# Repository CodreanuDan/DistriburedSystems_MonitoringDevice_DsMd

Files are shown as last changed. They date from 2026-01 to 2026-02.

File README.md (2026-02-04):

# Distributed Monitoring and Control System  

## 1. Overview  
IoT-based Smart Home solution using two independent ESP32 nodes communicating in real-time via MQTT. The system monitors environmental parameters (temperature, air quality, light) and automatically controls power loads (DC motor, LED) with hysteresis logic or manual override through a Node-RED dashboard.

Block Diagram  
*System block diagram showing sensor-actuator distribution and MQTT communication*

## 2. Hardware  
Node 1 handles power control and consumption monitoring. Node 2 performs environmental data acquisition and visual feedback.

Breadboard  
*Full breadboard assembly of both nodes*

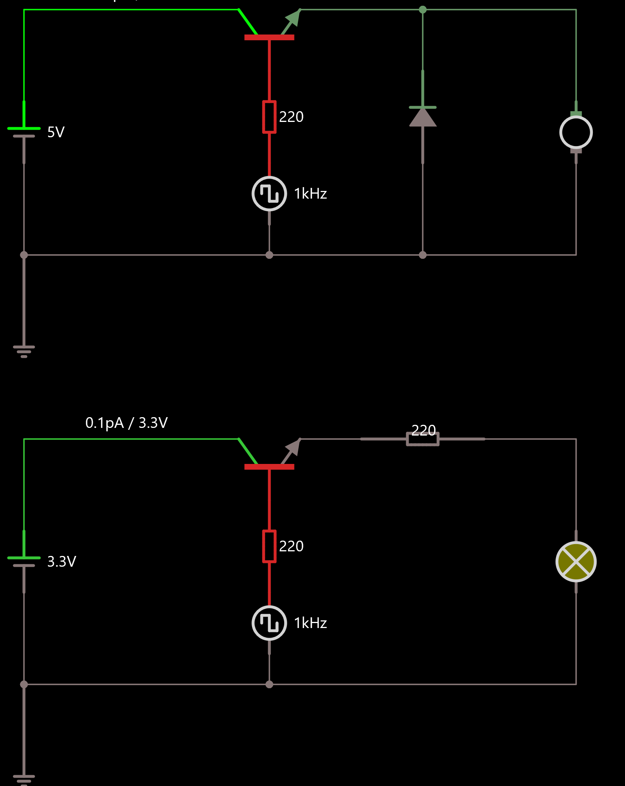
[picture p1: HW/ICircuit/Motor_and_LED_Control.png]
Motor Control Circuit; LED Control Circuit
  
*TIP142 Darlington transistor driver for DC motor with flyback diode protection; S8050 NPN transistor driver for LED control*

## 3.1 Software – ESP32 Nodes  

SW Diagram Node 1  
*Software flow for Node 1 (motor control, MAX471, LDR, WiFi/MQTT, LCD, button FSM)*

SW Diagram Node 2  
*Software flow for Node 2 (BME680 task, LED dimmer, WiFi/MQTT, LCD, button FSM)*

## 3.2 MQTT & Node-RED Dashboard  

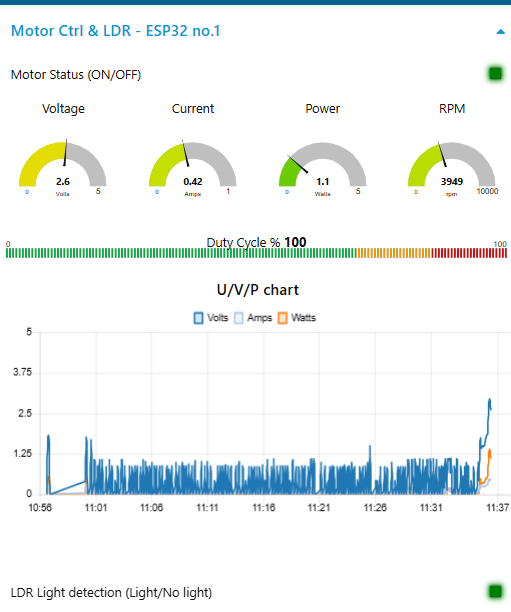
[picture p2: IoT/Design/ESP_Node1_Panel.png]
Dashboard Node 1 – Motor & LDR
  
*Real-time motor power, current, voltage and LDR status monitoring*

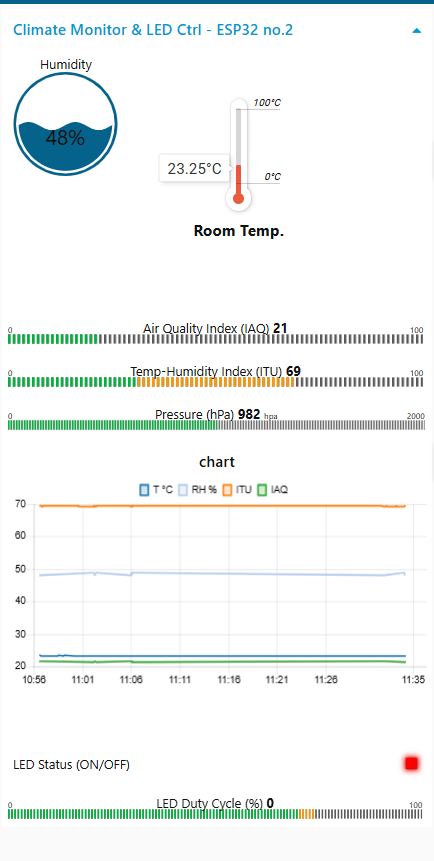
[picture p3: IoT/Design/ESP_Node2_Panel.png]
Dashboard Node 2 – Climate & LED
  
*Temperature, humidity, IAQ and LED control visualization*

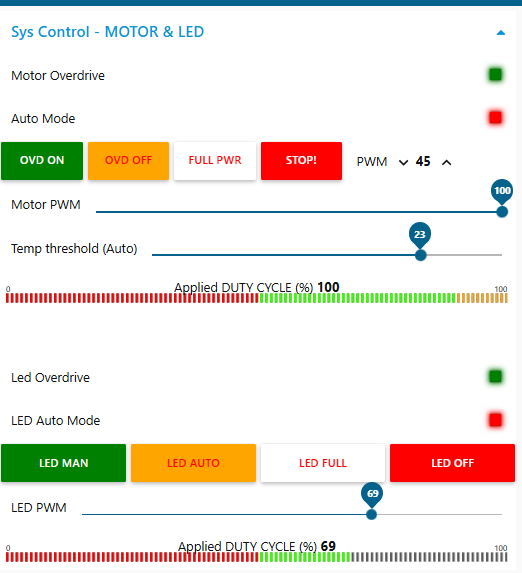
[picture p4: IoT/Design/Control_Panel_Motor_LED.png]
Dashboard Control – Motor & LED
  
*Manual/Auto mode selection and direct control buttons for motor and LED*

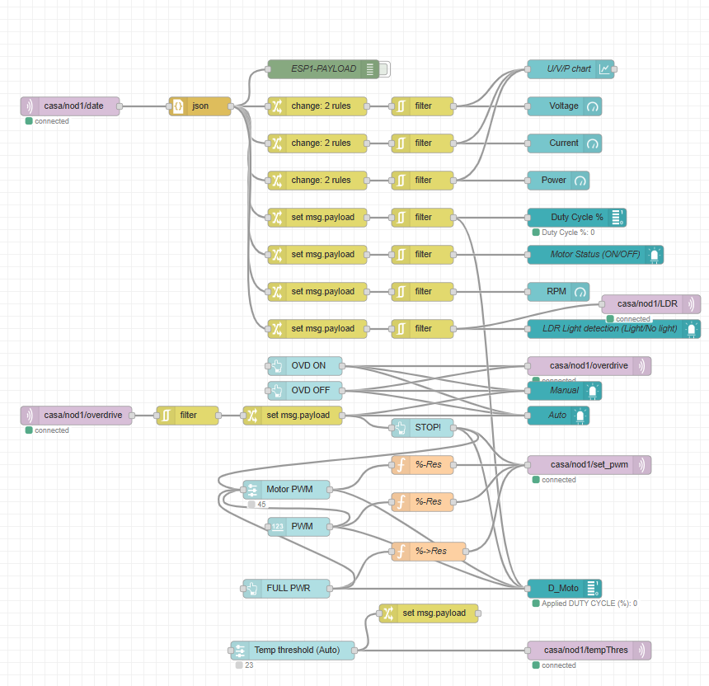
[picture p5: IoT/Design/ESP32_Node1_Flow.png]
Node-RED Flow ESP1
  
*Data processing and dashboard flow for Node 1*

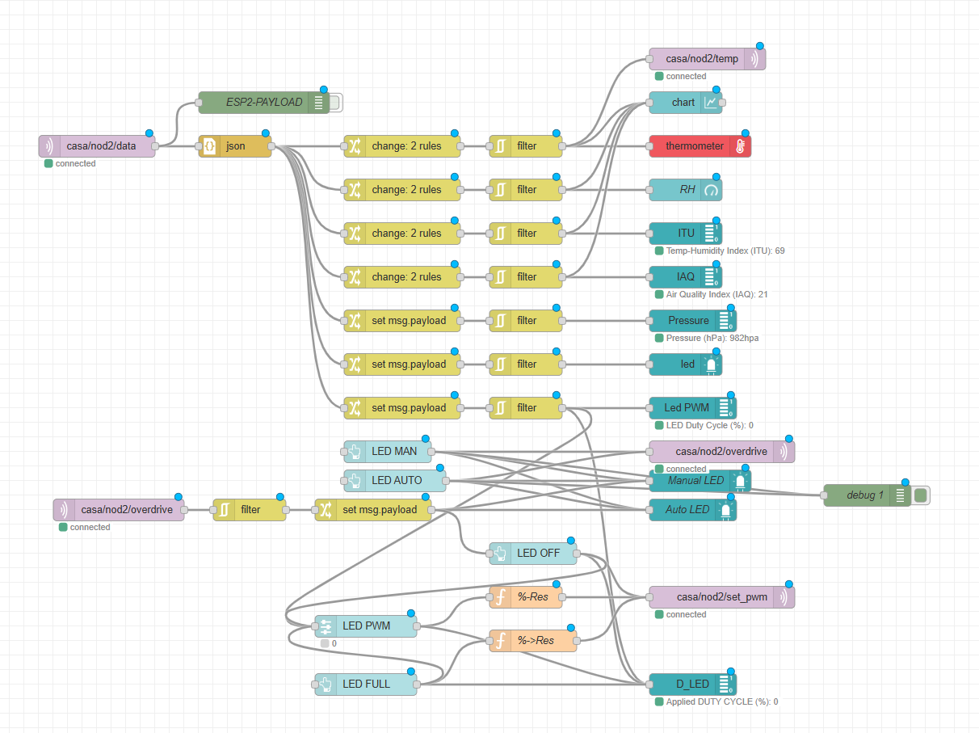
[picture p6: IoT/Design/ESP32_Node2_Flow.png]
Node-RED Flow ESP2
  
*Sensor data processing and LED command flow for Node 2*

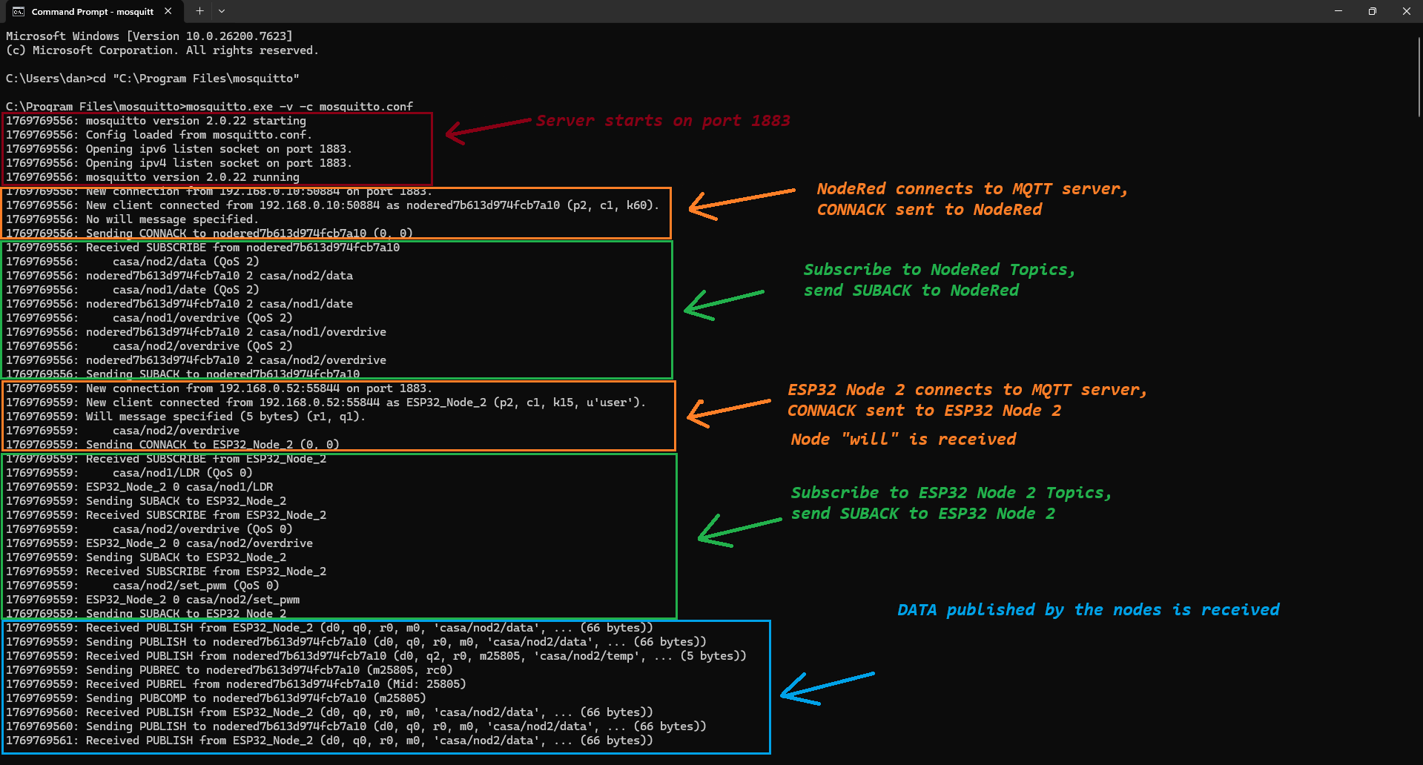
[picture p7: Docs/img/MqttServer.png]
MQTT Broker Workflow
  
*MQTT communication flow between ESP32 nodes and Node-RED dashboard*

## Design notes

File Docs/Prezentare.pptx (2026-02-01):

## Sistem distribuit de monitorizare si control

Codreanu Dan

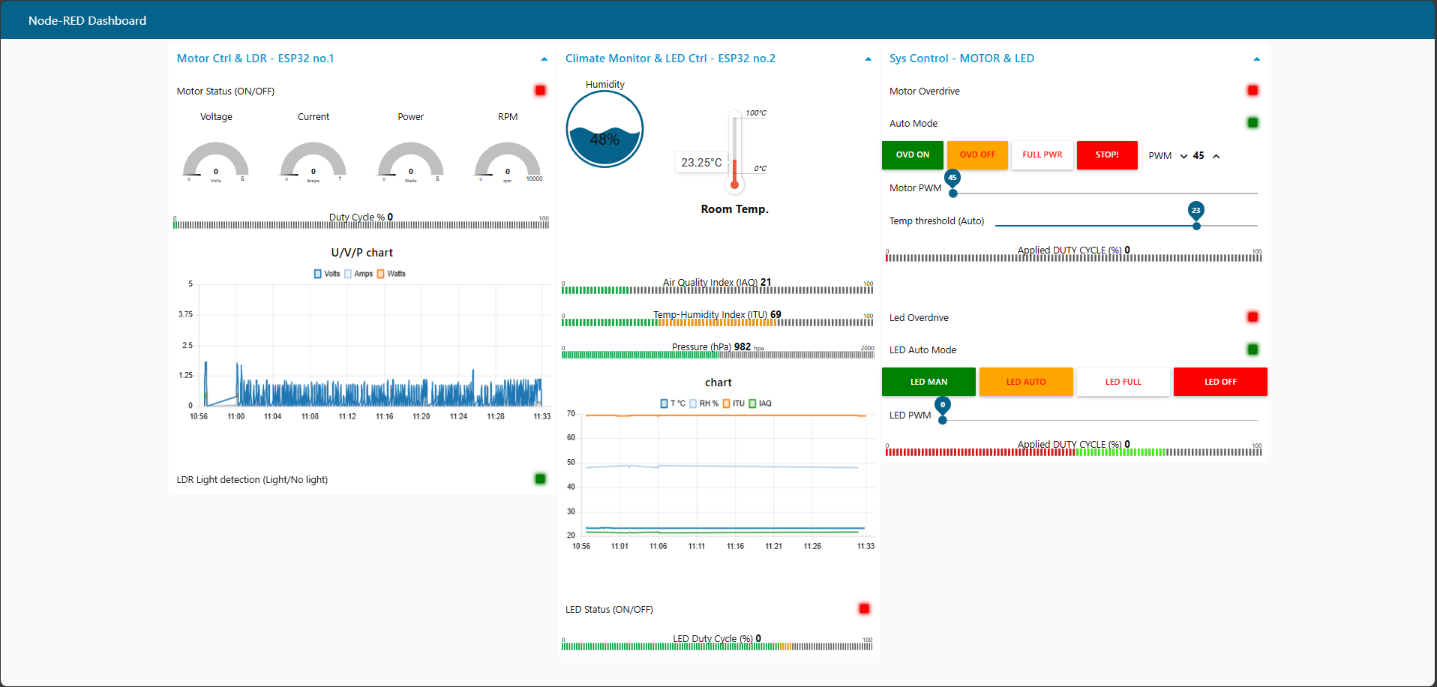
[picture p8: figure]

## Schema bloc

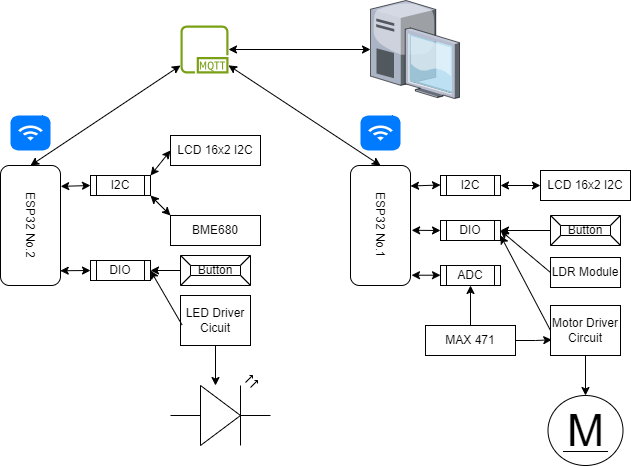
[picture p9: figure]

## Implementare fizica

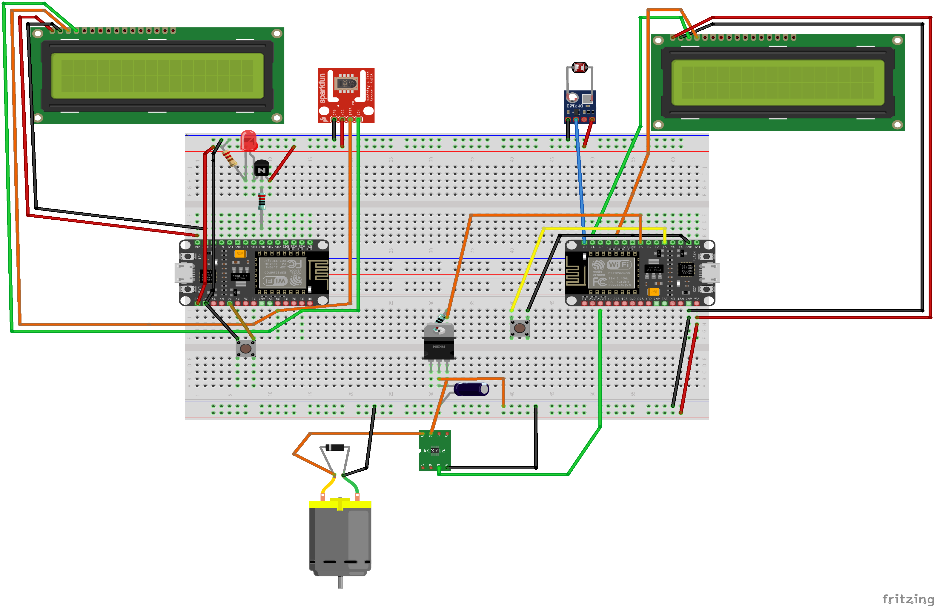
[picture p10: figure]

## Aplicatie Nod 1

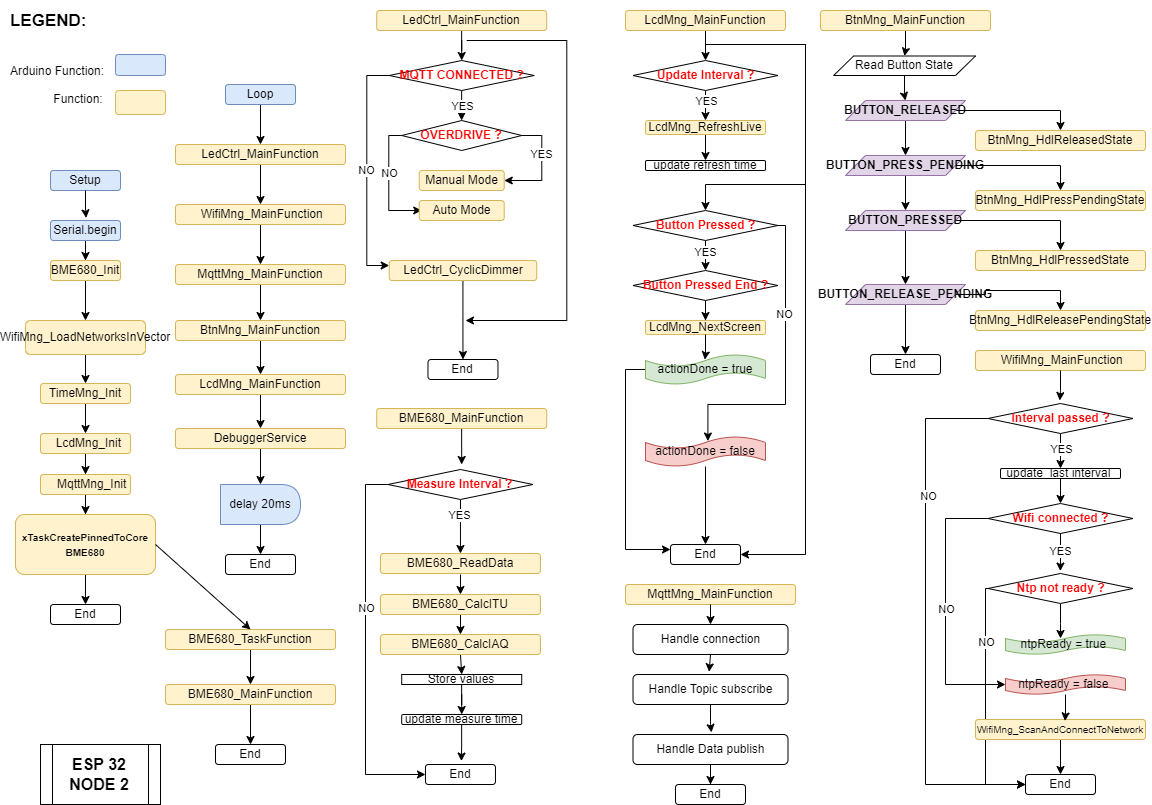
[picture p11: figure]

Aplicatie Nod 2

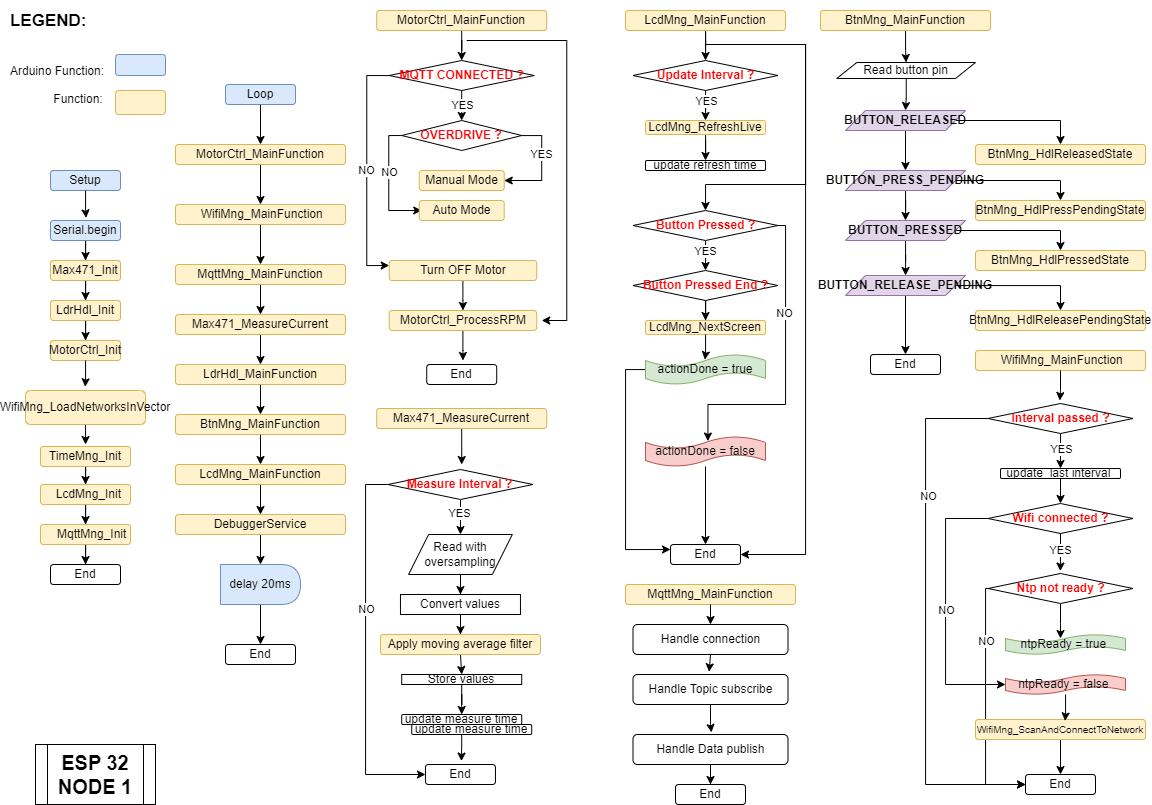
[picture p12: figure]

## Panou comanda

## Flow Nod 1


Flow Nod 2


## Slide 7


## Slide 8


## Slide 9


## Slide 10

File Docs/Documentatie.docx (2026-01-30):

Sistem distribuit de monitorizare si control

Codreanu Dan

Capitolul 1 Descriere

Sistemul propus reprezinta o solutie integrata de monitorizare si control ambiental de tip Smart Home, bazata pe arhitectura IoT (Internet of Things). Scopul principal este automatizarea climatizarii si a iluminatului intr-un spatiu interior prin comunicarea intre doua noduri inteligente independente (ESP32) care fac schimb de date in timp real prin protocolul MQTT. Sistemul nu doar monitorizeaza parametrii de mediu (temperatura, calitate aer, lumina), ci si actioneaza asupra unor sarcini de putere (motor DC, LED) intr-un mod eficient, protejand componentele hardware prin logica de control avansata.

1.1 Detalii Tehnice: Nodul 1 (Control Putere si Executie)

Acest nod este responsabil pentru gestionarea elementelor mecanice si monitorizarea consumului de energie.

- Actionare Motor: Utilizeaza un tranzistor Darlington TIP142 pentru a controla un motor DC prin PWM (1 kHz).
- Monitorizare Energie: Senzorul MAX471 masoara in timp real curentul si tensiunea consumata de motor, oferind date critice despre sarcina sistemului.
- Senzor LDR Digital: Monitorizeaza pragul de luminozitate ambientala.
- Interfata Locala: Un ecran LCD afiseaza statusul motorului, consumul de curent si starea conexiunii WiFi/MQTT.

1.2 Detalii Tehnice: Nodul 2 (Monitorizare Mediu si Feedback)

Acest nod functioneaza ca unitate de achizitie date si indicator vizual.

- Senzor BME680: Senzor de inalta precizie care furnizeaza date despre temperatura, umiditate, presiune atmosferica si calitatea aerului (IAQ - Indoor Air Quality).
- Sistem Iluminat: Un LED de controlat prin transistor prin PWM, a carui stare depinde de datele primite de la senzorul LDR de pe Nodul 1.
- Interfata Locala: Ecran LCD dedicat pentru afisarea telemetriei de mediu primite de la BME680 si starea conexiunii WiFi/MQTT.

1.3 Logica de Control si Comunicare

Interactiunea dintre cele doua noduri este mediata de un broker MQTT si un dashboard Node-RED:

1. Control Automat Motor (Histerezis): Nodul 1 primeste temperatura de la Nodul 2 si ajusteaza viteza motorului in functie de diferenta fata de pragul setat.
2. Control Automat LED : Cand senzorul LDR (Nod 1) detecteaza intuneric, se trimite o comanda MQTT catre Nodul 2 pentru a aprinde LED-ul local.
3. Supraveghere: Node-RED serveste drept interfata centrala de comanda, unde utilizatorul poate trece sistemul din modul "Auto" in "Manual" (Overdrive).

Capitolul 2 Hardware

Acest capitol descrie componentele electronice utilizate si modul in care acestea au fost integrate pentru a realiza cele doua noduri de control si monitorizare.

2.1. Unități de Procesare și Comunicare

Sistemul utilizează două unități ESP32, configurate să comunice prin protocolul MQTT. Alegerea acestora a fost motivată de prezența modulelor WiFi integrate și a pinilor hardware dedicați pentru PWM și ADC (conversie analog-digitală, Fig. 2.1).

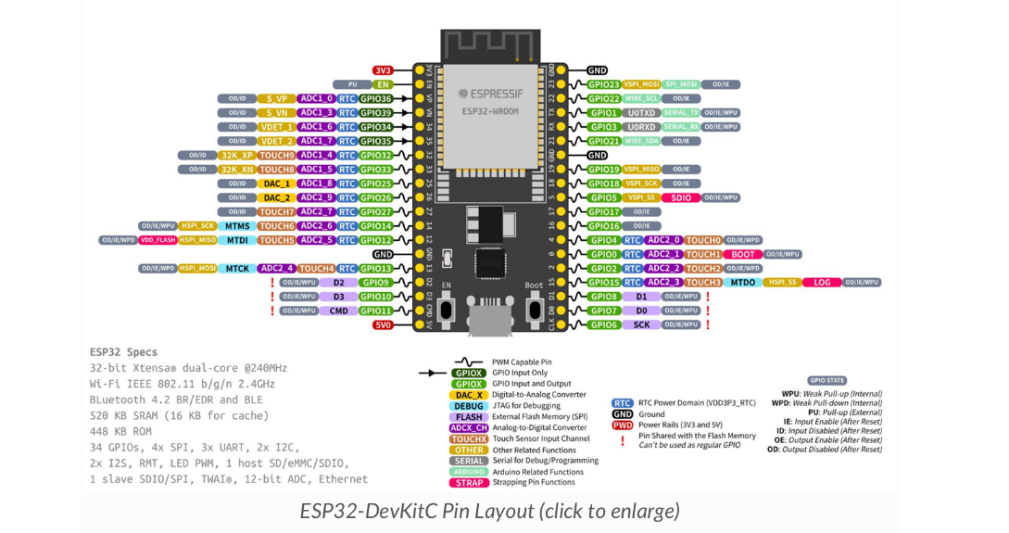
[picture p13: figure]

Fig 2.1 : ESP 32

2.2. Senzori (Achiziție Date)

Sistemul colectează date din mediul exterior prin trei senzori principali:

- BME680: Un senzor complex de mediu care măsoară temperatura, umiditatea, presiunea atmosferică și rezistența gazului (pentru calitatea aerului Tabel 2.1 si Fig. 2.2).

Parametru | Specificatie
Interfata de comunicare | I2C (pana la 3.4 MHz) si SPI
Gama masurare Temperatura | -40°C ... +85°C
Rezolutie Temperatura | 0.01 °C
Toleranta Temperatura | ±0.5 °C (la 25°C)
Gama masurare Umiditate | 0% ... 100% r.H.
Toleranta Umiditate | ±3% r.H.
Gama Presiune Barometrica | 300 ... 1100 hPa
Calitate Aer (IAQ) | 0 ... 500 (VOC - Compusi Organici Volatili)

Tabel 2.1: Specificatii BME 680

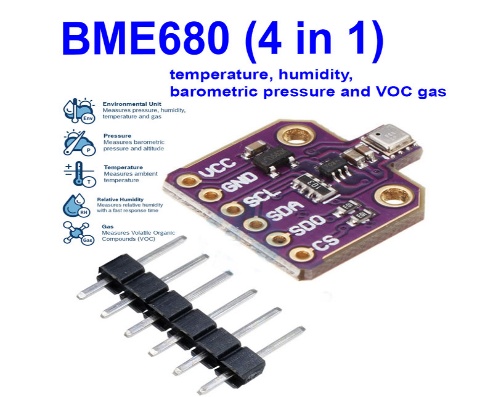
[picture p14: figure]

Fig. 2.2: Senzor BME 680

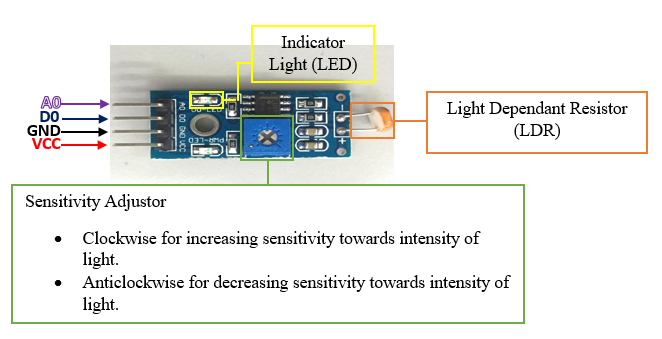
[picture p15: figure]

- LDR (Light Dependent Resistor): Modul digital care monitorizează intensitatea luminii ambientale pentru controlul automat al iluminatului (Fig. 2.2.)

Fig. 2.3: Modul sensor LDR

- MAX471: Senzor specializat pentru măsurarea tensiunii și a curentului (până la 3A). Acesta oferă feedback vital despre consumul motorului și eficiența tranzistorului de putere (Tabel 2.2 si Fig. 2.3).

Parametru | Specifitcatie
Interfata de comunicare | Analogica (Tensiune proportionala cu I si V)
Gama masurare Curent | 0A ... 3A (Sensibilitate 1V / 1A)
Gama masurare Tensiune | 3V ... 36V (Divizor intern 1:5)
Gama masurare Tensiune | ±2%
Rezolutie (pe ESP32) | 12-bit ADC (aprox. 0.8mA per unitate)
Functie principala | Monitorizare consum motor si detectie Back EMF

Tabel 2.2: Specificatii MAX 471

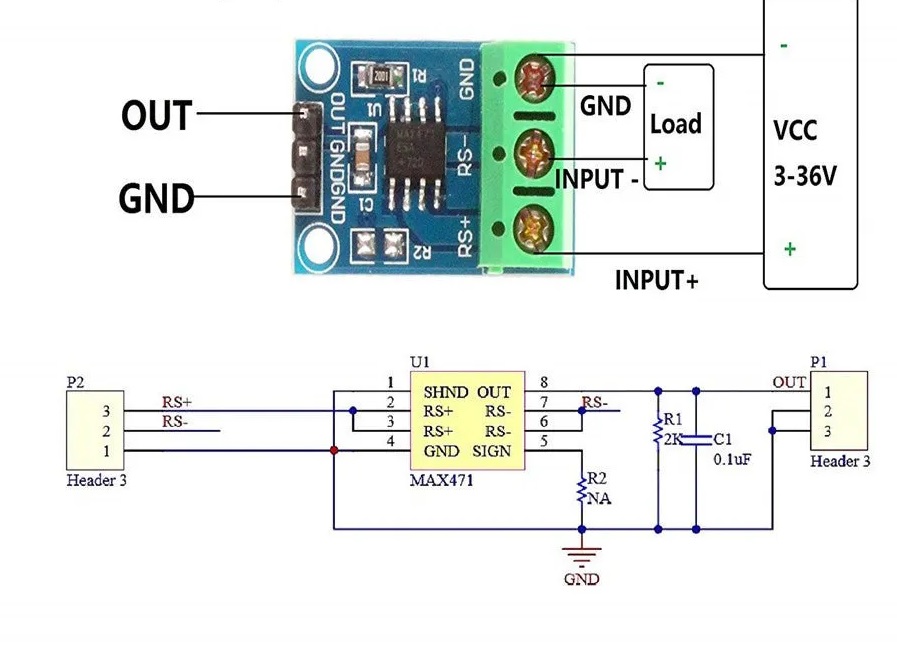
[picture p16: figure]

Fig. 2.3: Senzor MAX 471 cu schema de cablare

2.3. Actuatori și Circuite de Comandă

Elementele de execuție sunt controlate prin tranzistori pentru a izola microcontrolerul de sarcinile de putere:

1. Sistemul de Răcire (Motor DC):
  - Utilizează un tranzistor Darlington TIP142 (Fig. 2.4).
  - Motorul are o forță nominală de 10 g*cm (aprox. 0.139 oz*in).
  - Include o diodă Flyback pentru protecție împotriva tensiunii electromotoare de autoinducție (Back EMF) generate la comutația PWM.
2. Sistemul de Iluminat (LED):
  - Utilizează un tranzistor NPN S8050 (Ic max 700mA, Fig. 2.4).
  - Permite controlul intensității luminoase fără a depăși limita de curent a pinilor ESP32.

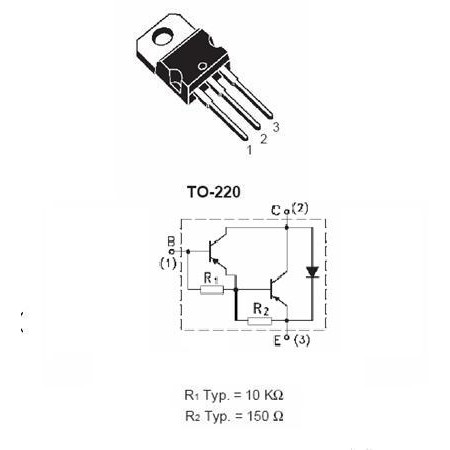
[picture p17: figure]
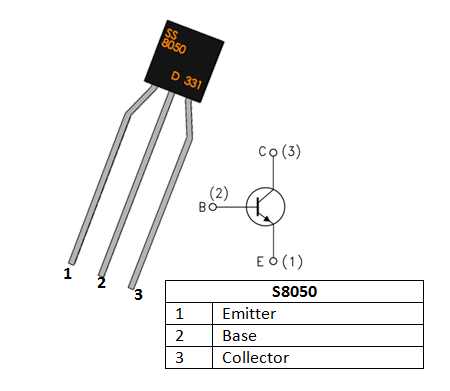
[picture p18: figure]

Fig. 2.4: Tranzistori TIP142 si S8050

2.4. Interfețe de Afișare

Sistemul dispune de două ecrane LCD 16x2 cu module I2C, care oferă feedback vizual direct (Fig 2.5) :

- Afișarea telemetriei de mediu (BME680).

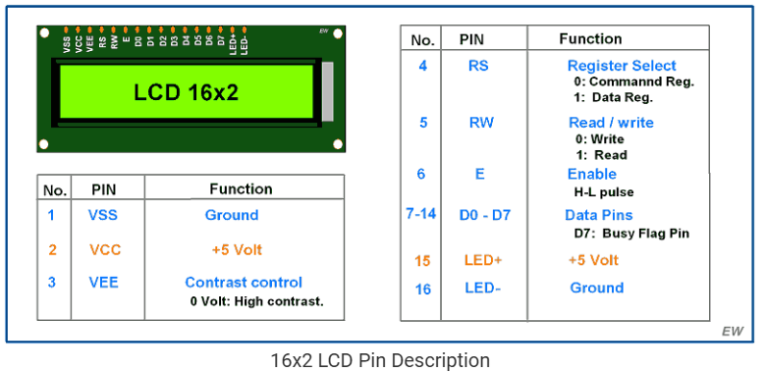
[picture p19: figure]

- Monitorizarea parametrilor electrici (V, mA, W) și a treptei PWM active.

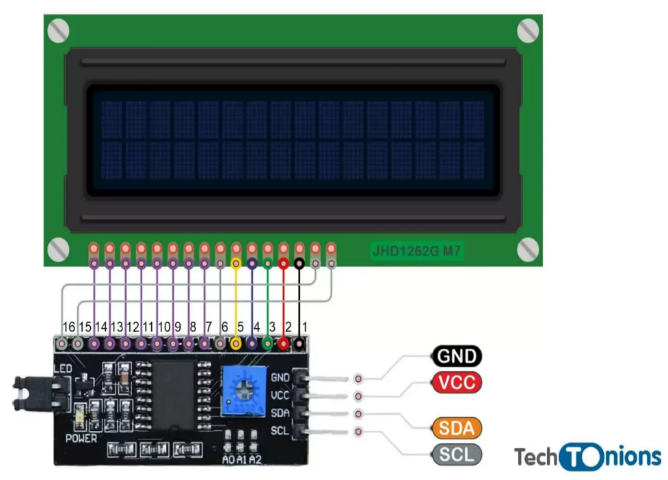
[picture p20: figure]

Fig. 2.5: Ecran LCD 16x2 LCD

2.5. Arhitectura si Conexiuni Hardware

Aceasta sectiune descrie modul in care componentele individuale interactioneaza pentru a forma un sistem unitar.

2.5.1. Diagrama Bloc a Sistemului

Diagrama bloc prezinta organizarea logica a componentelor. Aceasta pune accent pe distributia senzorilor si a elementelor de executie, fara a detalia nivelurile de tensiune, evidentiind rolul central al brokerului MQTT in comunicarea dintre cele doua unitati ESP32. (Fig. 2.6)


Fig. 2.6: Diagrama Bloc a Sistemului

2.5.2. Layout-ul General (Breadboard)

Implementarea fizica pe breadboard prezinta implementarea fizica a proiectului. (Fig. 2.7)


Fig. 2.7: Implementarea fizica pe breadboard

2.5.3. Circuitele de Comanda (Drivere Actuatori)

Sistemul utilizeaza doua circuite de comanda dedicate pentru a izola microcontrolerul de sarcinile electrice mari: (Fig. 2.8)

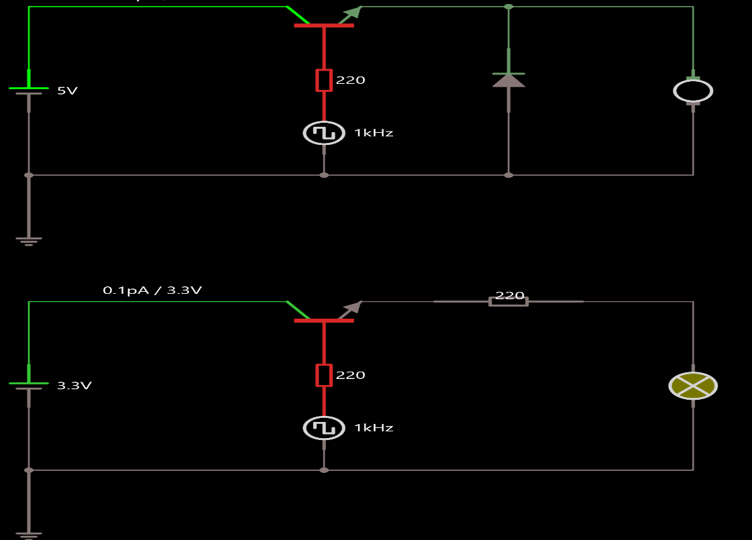
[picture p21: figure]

Fig. 2.8: Implementarea fizica pe breadboard

A. Circuitul de Comanda Motor (TIP142):

- Tranzistor: Darlington NPN TIP142.
- Functie: Controlul vitezei prin PWM (1 kHz).
- Protectie: Include o dioda Flyback montata in paralel cu motorul pentru a absorbi varfurile de tensiune generate de inductanta motorului (Back EMF).
- Monitorizare: Senzorul MAX471 este inseriat in acest circuit pentru a masura curentul consumat in timp real.

B. Circuitul de Comanda LED (S8050):

- Tranzistor: NPN S8050 de mica putere.
- Functie: Comutarea sau reglarea intensitatii LED-ului pe baza datelor primite de la senzorul LDR.
- Avantaj: Protejeaza pinul GPIO al ESP32, permitand un curent de operare mai mare decat cei 12-20mA pe care ii poate furniza direct microcontrolerul.

Nota Tehnica: Cuplul nominal al motorului este de 10 g*cm (aprox. 0.139 oz*in). In cadrul testelor, s-a observat ca la valori PWM sub 45%, forta motorului este limitata de frecarea interna si de caderea de tensiune de aprox. 1.2V pe tranzistorul TIP142.

Capitolul 3: Arhitectura Software

Sistemul utilizeaza o arhitectura modulara. Fiecare componenta hardware este gestionata de un modul software dedicat, facilitand testarea si depanarea independenta.

3.1. Module Specifice Nod 1 (Figura 3.1)

- Setup & Loop: Initializeaza perifericele(Serial.begin(115200), Max471_Init(MAX_471_PIN, ADC_RESOLUTION, ADC_0db), LdrHdl_Init(), MotorCtrl_Init(),WifiMng_LoadNetworksInVector(),TimeMng_Init(),LcdMng_Init(),MqttMng_Init()) si ruleaza secvential functiile de control la un interval de 20ms pentru a reseta Watchdog timer-ul si a nu bloca procesorul.
- Motor Control (MotorCtrl_MainFunction()): Verifica starea conexiunii MQTT si modul de operare (Manual[Overdrive:True]/Auto[Overdrive:False]). Calculeaza turatia aproximativa (MotorCtrl_ProcessRPM()) , starea curenta a motorului (MotorCtrl_CheckMotorStat(targetDuty)) si gestioneaza pornirea/oprirea motorului.
- Max471_Hdl(): Realizeaza achizitia de date prin oversampling (citiri multiple pentru precizie), converteste valorile analogice si aplica un filtru de medie mobila (moving average filter) pentru a elimina zgomotul electric cauzat de motor.
- LdrHdl_MainFunction(): Monitorizeaza intrarea digitala a senzorului de lumina pentru a determina pragul de zi/noapte.

3.2. Module Specifice Nod 2 (Figura 3.2)

- Setup & Loop: Pe langa initializarile standard, acest nod creeaza un Task dedicat pentru BME680 (xTaskCreatePinnedToCore), profitand de arhitectura dual-core a ESP32 pentru a nu bloca bucla principala in timpul citirilor lungi ale senzorului.
- LedCtrl_MainFunction(): Gestioneaza starea LED-ului. Verifica starea conexiunii MQTT si modul de operare (Manual[Overdrive:True]/Auto[Overdrive:False]). In modul "Auto", foloseste un sistem de tip Cyclic Dimmer (LedCtrl_CyclicDimmer()) pentru a regla intensitatea luminii in mod progresiv.
- BME680_TaskFunction(void * pvParameters) & BME680_MainFunction(): Citeste datele brute de la senzor, calculeaza indicii de confort (ITU) si calitatea aerului (IAQ), apoi stocheaza valorile pentru a fi publicate.

3.3. Module Comune (Partajate intre Noduri)

Aceste module asigura infrastructura de comunicatie si interfata cu utilizatorul pe ambele dispozitive:

- WifiMng_MainFunction(): Gestioneaza scanarea si conectarea si reconectarea automata la retea. Include logica de verificare a timpului prin NTP (Network Time Protocol, TimeMng_GetTimestamp()) pentru a sincroniza evenimentele.
- MqttMng_MainFunction(): Subscrie la topicurile de comanda si publica telemetria (datele senzorilor) catre broker. Gestioneaza reconectarea automata in caz de pierdere a semnalului.
- BtnMng_MainFunction(BTN_PIN, BtnMng_debounceTime): Implementeaza o masina de stare pentru tratarea apasarilor (Released, Press Pending, Pressed, Release Pending), eliminand zgomotul mecanic prin debounce.
- LcdMng_MainFunction(): Controleaza afisajul. Permite navigarea intre mai multe ecrane de date la apasarea butonului si actualizeaza informatiile in timp real la intervale setate.

3.4. Debugger Service

Fiecare nod ruleaza un serviciu de monitorizare (DebuggerService()) care trimite catre consola Seriala un raport detaliat despre starea interna a sistemului, facilitand diagnosticarea rapida fara a fi nevoie de acces fizic la ecranele LCD.

3.5. Optimizari si Tehnici de Control Avansate

Pentru a asigura stabilitatea sistemului si protectia hardware-ului, au fost implementate urmatoarele solutii software:

3.5.1. Filtrarea Datelor: Moving Average Filter si ADC Vref 1.1V

Senzorul MAX471 este montat in proximitatea motorului, fiind expus la zgomot electromagnetic. Pentru a obtine o citire stabila a curentului si a tensiunii:

- S-a utilizat tehnica oversampling-ului, citind senzorul de mai multe ori intr-un interval scurt.
- Datele sunt procesate printr-un filtru de medie mobila (Moving Average), care elimina varfurile (spike-urile) cauzate de comutatia PWM si de Back EMF, oferind o valoare "curata" pe LCD si in Dashboard.
- Tensiunea de referinta a ADC-ului este setata la 1.1V (ADC_0db) deoarece motorul foloist nu va trage mai mult de 1A, si legea de conversie fiind 1A la 1V, ajuta la o masurare mai optima.

3.5.2. Managementul PWM (1 kHz):

Frecventa semnalului PWM pentru controlul motorului a fost setata la 1 kHz cu o rezolutie de 8 biti:

- De ce 1 kHz? Aceasta frecventa este suficient de mare pentru a asigura o rotatie fluida si pentru a evita tiuitul audibil al motorului, dar suficient de mica pentru a reduce pierderile prin incalzire pe tranzistorul TIP142.
- Controlul LED-ului de pe al doilea nod utilizeaza tot PWM prin functia analogWrite(), permitand tranzitii line de luminozitate (dimming) gestionate de tranzistorul S8050.

3.5.3. Functia de Kickstart: MotorCtrl_Kickstart(targetDuty);

Motoarele DC mici au o frecare statica ce poate impiedica pornirea la valori mici de PWM (ex. 45%).

- Logica de control include un mecanism de Kickstart: la fiecare pornire din starea "Stop", motorul primeste un impuls de la 100% PWM pana la turatia setata pentru o durata foarte scurta (aprox. 100-200ms).
- Acest impuls ofera energia necesara pentru a invinge inertia, dupa care sistemul revine imediat la pragul tinta (ex. 45% sau 55%).

3.5.4. Executie Non-Blocking

O caracteristica esentiala a codului este faptul ca toate functiile sunt non-blocking:

- Nu s-a utilizat functia delay() in interiorul modulelor (cu exceptia micii pauze de 20ms din loop pentru stabilitatea generala).
- Gestionarea timpului pentru citirea senzorilor (BME680, MAX471) sau trimiterea datelor prin MQTT se face prin compararea valorilor millis().
- Acest lucru permite ESP32-ului sa raspunda instantaneu la apasarea butoanelor sau la mesajele primite de la server, chiar daca in acelasi timp proceseaza datele de mediu sau calculeaza media mobila.


Fig 3.1: Aplicatie ESP32 Nod 1


Fig 3.2: Aplicatie ESP32 Nod 2

Capitolul 4: Interfata de Control (Node-RED si MQTT)

Aceasta sectiune descrie infrastructura software de nivel inalt care asigura comunicarea, stocarea datelor si interfata grafica pentru utilizator (Dashboard).

4.1. Serverul MQTT (Mosquitto)

Serverul MQTT actioneaza ca un "broker" (intermediar) de mesaje. Acesta primeste datele de la cele doua ESP32 si le redirectioneaza catre Node-RED.

- Instalare si Rulare: S-a utilizat Eclipse Mosquitto. Instalarea pe sistemul gazda (ex: Raspberry Pi sau PC) s-a realizat prin managerul de pachete, fiind configurat sa ruleze ca serviciu de fundal pe portul standard 1883, logare tip “anonimous” pentru a nu fi nevoie de user parola si a facilita protiparea


- Rol: Asigura decuplarea completa intre noduri; ESP1 nu are nevoie sa stie adresa IP a ESP2, ambele comunicand doar cu adresa serverului MQTT. (Fig. 4.1)

Fig 4.1: Functionare Server MQTT

4.2. Platforma Node-RED

Node-RED este instrumentul de programare vizuala utilizat pentru a procesa fluxurile de date si pentru a crea interfata de control (Dashboard).

- Instalare: Rulat in mediul Node.js, instalat via npm.
- Logica de Flux (Flows): Aici am integrat diagramele de noduri pentru cele doua ESP-uri.
  - Flow ESP 1: Noduri de intrare MQTT pentru U, I, P si RPM, conectate la functii de procesare si elemente grafice.( Fig.4.2)
  - Flow ESP 2: Noduri pentru preluarea telemetriei BME680 (T, RH, IAQ, ITU) si transmiterea comenzilor catre LED. (Fig.4.3)


Fig 4.2: Flow ESP32 Node 1


Fig 4.3: Flow ESP32 Node 2

4.3. Prezentarea Dashboard-ului (Interfata Utilizator)

Dashboard-ul este impartit in trei panouri principale pentru o monitorizare clara si un control precis.

4.3.1. Panoul 1: Monitorizare Energie si Motor (Nod 1)

Acest panou este dedicat performantei electrice a motorului DC. (Fig. 4.4)

- Instrumente de masura: Gauge-uri si grafice de tip "History" pentru Tensiune (U), Curent (I), Putere (P) si RPM.
- Vizualizare Comparativa: Chart (grafic liniar) care suprapune valorile U, I si P pentru analiza eficientei.
- Indicatori Stare: O bara progresiva pentru nivelul de Duty Cycle al motorului si un LED virtual care semnalizeaza daca motorul este alimentat.


Fig 4.4: Panoul 1: Monitorizare Energie si Motor (Nod 1)

4.3.2. Panoul 2: Monitorizare Mediu si Senzori (Nod 2)

Ofera o privire de ansamblu asupra conditiilor ambientale citite de BME680 si starea luminilor. (Fig. 4.5)

- Indicatori Vizuali: "Fill tank" pentru Umiditate Relativa (RH), termometru vertical pentru Temperatura (T), bare de progres pentru calitatea aerului (IAQ), indicele de confort (ITU) si presiune.
- Istoric Date: Grafice dedicate pentru evolutia RH, T, IAQ si ITU.
- Status Sistem: Bara pentru Duty Cycle LED, LED-uri virtuale pentru starea Motor ON/OFF si un indicator pentru detectia de lumina (zi/noapte) primita de la LDR.


Fig 4.5: Panoul 2: Monitorizare Mediu si Senzori (Nod 2)

4.3.3. Panoul 3: Consola de Comanda (Control Motor si LED)

Acesta este panoul interactiv unde utilizatorul poate interveni asupra sistemului. (Fig.4.6)

Control Motor:

- Moduri: LED-uri de stare pentru modul Auto (ON/OFF) si Manual (ON/OFF).
- Comenzi Rapide: 4 butoane pentru Overdrive ON, Overdrive OFF, Full Power si Stop.
- Reglaj Fin: Control numeric pentru setarea exacta a turatiei in plaja de siguranta (45-75%).
- Interfata Tactila: Sliding bar pentru controlul vitezei (45-100%) si un sliding bar pentru setarea pragului de temperatura (Threshold 0-30°C) utilizat in modul Auto.

Control LED:

- Moduri: LED-uri pentru modul Auto/Manual.
- Comenzi Rapide: Butoane pentru Overdrive, Full Dimm (intensitate maxima) si OFF.
- Reglaj: Control numeric (45-75%) si sliding bar pentru ajustarea PWM-ului de la 0 la 100%.


Fig 4.5: Panoul 3: Consola de Comanda (Control Motor si LED)

Capitolul 5: Concluzii

Proiectul a demonstrat succesul implementării unui sistem de monitorizare și control de tip Smart Home, utilizând o arhitectură distribuită bazată pe două unități ESP32 și protocolul de comunicație MQTT.

5.1. Realizări Proiectului

- Integrare Hardware-Software: S-a reușit controlul eficient al sarcinilor de putere (motor DC și LED) prin utilizarea tranzistorilor TIP142 și S8050, protejând în același timp integritatea microcontrolerelor.
- Fiabilitatea Datelor: Implementarea filtrului de medie mobilă (Moving Average Filter) și a tehnicii de oversampling a permis obținerea unor citiri stabile de curent și tensiune, în ciuda zgomotului electromagnetic generat de motor.
- Control Inteligent: Algoritmul de control cu trei praguri și funcția de Kickstart au asigurat o funcționare fluidă a sistemului de răcire, eliminând problemele cauzate de frecarea statică a motorului la turații mici.
- Monitorizare Centralizată: Interfața Node-RED oferă o experiență de utilizare intuitivă, centralizând telemetria complexă (BME680, MAX471, LDR) într-un dashboard vizual complet.

5.2. Avantajele Arhitecturii Adoptate

Utilizarea protocolului MQTT a permis o scalabilitate ridicată. Nodurile pot fi plasate în locații diferite, singura condiție fiind accesul la rețeaua WiFi, ceea ce transformă acest proiect într-o soluție viabilă pentru automatizări rezidențiale sau industriale ușoare.


Execuția de tip non-blocking și utilizarea multithreading-ului (pe ESP32 Node 2) garantează că sistemul rămâne receptiv la comenzile utilizatorului, indiferent de complexitatea calculelor de mediu efectuate în fundal.

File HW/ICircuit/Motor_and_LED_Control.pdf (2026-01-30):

# Motor_and_LED_Control

1/29/2026 1:58:46 PM

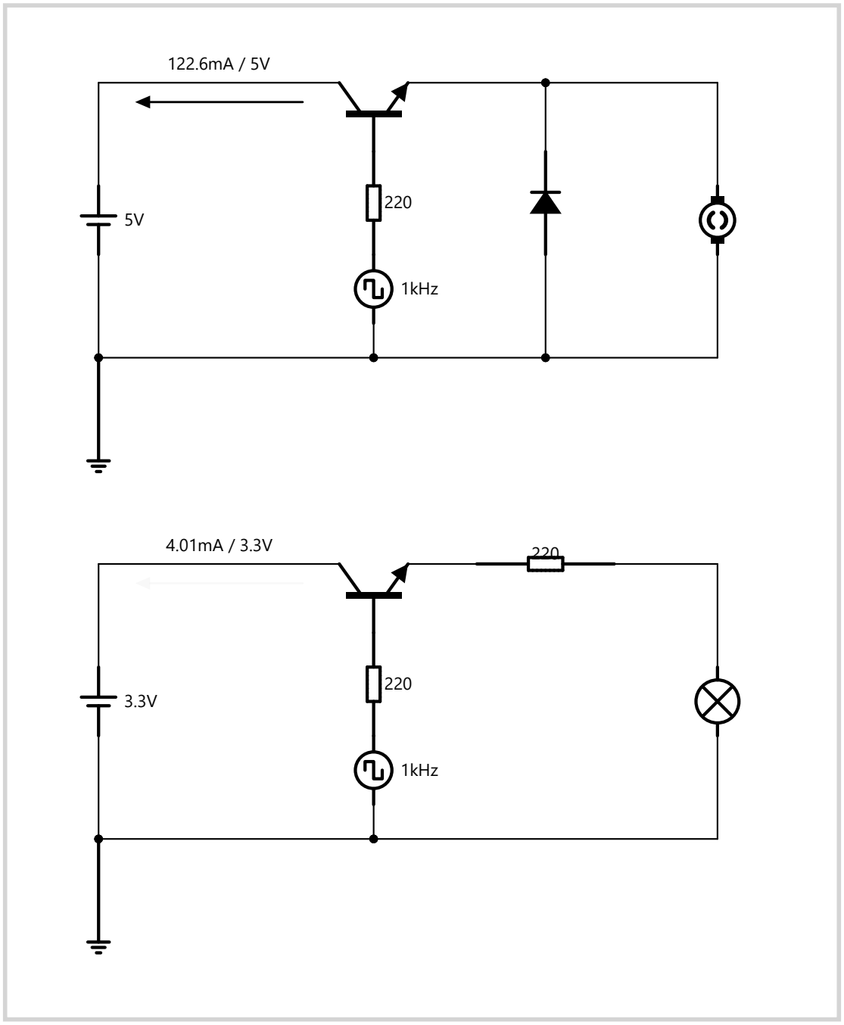
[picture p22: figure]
1kHz

# | Element | Parameters

2 | BJT Transistor (NPN) | Beta/hFE: 1k
1 | DC Motor | Nominal Voltage: 3, Free Running RPM: 200, Free Running Current: 70m, Stall Current: 600m, Stall Torque (oz in): 45, Inductance (H):
1 | DC Source | Voltage: 5, Waveform: DC
1 | DC Source | Voltage: 3.3, Waveform: DC
1 | Diode | Fwd Voltage @ 1A: 805.904783m
1 | Lamp | Nominal Power: 1m, Nominal Voltage: 3, Warmup Time (s): 40m, Cooldown Time (s): 40m
3 | Resistor | Resistance (Ω): 220
2 Square Wave Source Amplitude (V): 3.3, Waveform: Square Wave, Frequency (Hz): 1k, DC Offset: 0, Phase Offset (deg): 0, Duty Cycle (%): 50.0

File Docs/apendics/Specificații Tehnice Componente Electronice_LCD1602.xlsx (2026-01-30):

Parametru | Specificatie
Interfata de comunicare | I2C (prin driver PCF8574)
Rezolutie caractere | 16 coloane x 2 randuri
Tehnologie Display | STN, LCD Albastru cu Backlight Alb
Tensiune alimentare | 5V DC
Adresa I2C standard | 0x27 sau 0x3F
Control contrast | Potentiometru integrat pe spatele modulului

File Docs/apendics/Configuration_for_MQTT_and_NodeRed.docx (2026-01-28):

Configuration procedure for MQTT and NodeRed

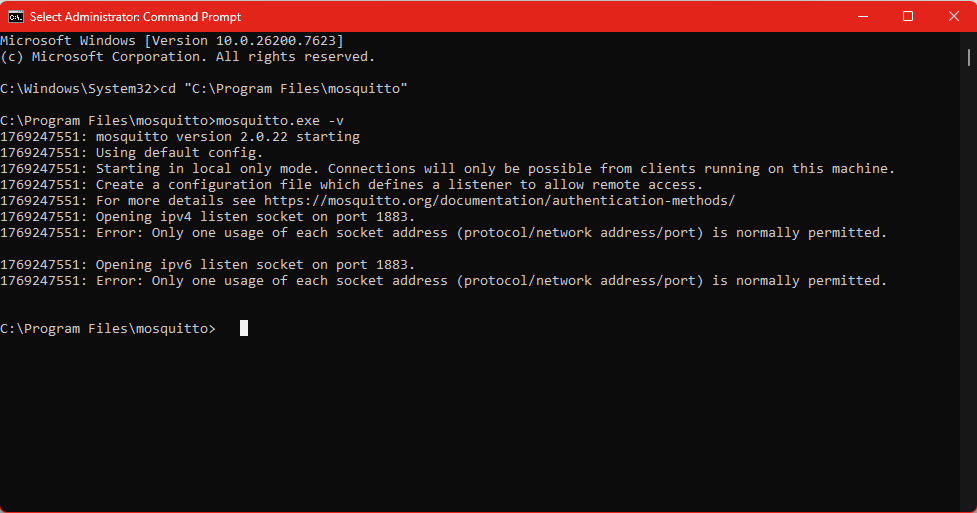
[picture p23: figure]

MQTT
Install Windows x64 version: Download | Eclipse Mosquitto (https://mosquitto.org/download/)
Open cmd.exe as Administrator
Task Manager -> Services -> mosquittoBroker -> Stop
C:\Program Files\mosquitto>netstat -ano | findstr :1883

C:\Program Files\mosquitto>mosquitto.exe -v -c mosquitto.conf

1769251385: mosquitto version 2.0.22 starting

1769251385: Config loaded from mosquitto.conf.

1769251385: Starting in local only mode. Connections will only be possible from clients running on this machine.

1769251385: Create a configuration file which defines a listener to allow remote access.

1769251385: For more details see https://mosquitto.org/documentation/authentication-methods/

1769251385: Opening ipv4 listen socket on port 1883.

1769251385: Opening ipv6 listen socket on port 1883.

1769251385: mosquitto version 2.0.22 running

C:\Program Files\mosquitto\mosquitto.conf:

Paste listener 1883

allow_anonymous true

The, in cmd:
cd "C:\Program Files\mosquitto"
mosquitto.exe -v -c mosquitto.conf

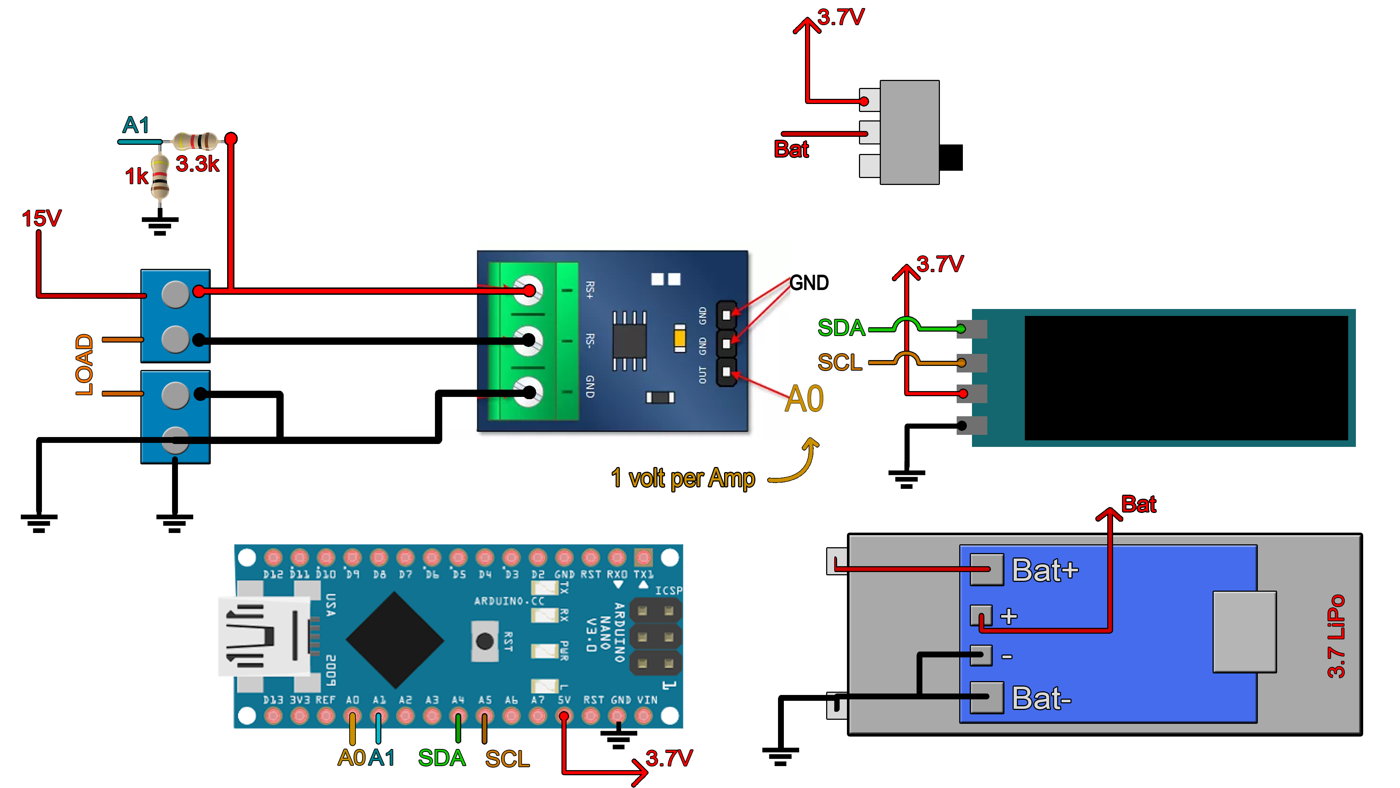
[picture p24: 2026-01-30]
Docs/img/sch_2.png

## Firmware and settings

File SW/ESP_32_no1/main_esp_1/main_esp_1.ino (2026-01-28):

/* main_esp_1.ino */

#include <freertos/FreeRTOS.h>
#include <freertos/task.h>
#include <freertos/semphr.h>

#include "WifiMng.h"
#include "MAX471_Hdl.h"
#include "BtnMng.h"
#include "LcdMenuMng.h"
#include "LdrHdl.h"
#include "TimeMng.h"
#include "MqttMng.h"
#include "MotorCtrl.h"

#define DBG_SERVICE_PRINT_INTERVAL 2000UL
void DebuggerService();


void setup() 
{
    Serial.begin(115200);
    delay(2000);

    Serial.println("=================> ESP NO.1 <==================");

    Max471_Init(MAX_471_PIN, ADC_RESOLUTION, ADC_0db);
    LdrHdl_Init();

    MotorCtrl_Init();

    WifiMng_LoadNetworksInVector();
    TimeMng_Init(); 
    LcdMng_Init();   
    MqttMng_Init(); 

}

void loop() 
{
    // MotorCtrl_TestFunction();
    MotorCtrl_MainFunction(); 
    // MotorCtrl_ApplyCyclicPWM(PWM_25);
    // MotorCtrl_ApplyPWM(PWM_75);
    // MotorCtrl_ProcessRPM();
    WifiMng_MainFunction(); 
    MqttMng_MainFunction(); 
    
    Max471_Hdl();
    LdrHdl_MainFunction();

    BtnMng_MainFunction(BTN_PIN, BtnMng_debounceTime);
    LcdMng_MainFunction();
    DebuggerService();

    delay(20); 
}

void DebuggerService()
{
    static unsigned long last_print_time = 0;
    unsigned long now = millis();

    if (now - last_print_time >= DBG_SERVICE_PRINT_INTERVAL)
    {

        /* Timestamp live */
        Serial.print("*Δt:"); Serial.print(now / 1000); Serial.print(" ");

        Serial.print("*IP:"); Serial.print((const char*)g_systemValues.wifi.ip); Serial.print(" ");
        Serial.print("RSSI:"); Serial.print(g_systemValues.wifi.rssi); Serial.print("dBm ");
        Serial.print("MQTT:"); Serial.print(g_systemValues.wifi.mqtt_connected); Serial.print(" ");

        Serial.print("*UL:"); Serial.print(g_systemValues.current.voltage_V); Serial.print("V ");
        Serial.print("IL:"); Serial.print(g_systemValues.current.current_A); Serial.print("A ");
        Serial.print("PM:"); Serial.print(g_systemValues.current.power_W); Serial.print("W ");
        Serial.print("ADC:"); Serial.print(g_systemValues.current.raw_adc); Serial.print(" ");

        Serial.print("*LDR:"); Serial.print(g_systemValues.light.level); Serial.print(" ");

        Serial.print("*RPM:");  Serial.print(g_systemValues.motor.rpm); Serial.print(" ");
        Serial.print("*TEMP:");  Serial.print(g_systemValues.mqtt.temp); Serial.print("C ");
        Serial.print("OVD:");  Serial.print(g_systemValues.mqtt.overdirve); Serial.print(" ");
        Serial.print("THR_SET:");  Serial.print(g_systemValues.mqtt.threshold); Serial.print(" ");
        Serial.print("PWM:");  Serial.print(g_systemValues.mqtt.pwm); Serial.print(" ");

        Serial.println();
        
        last_print_time = now;
    }
}
 

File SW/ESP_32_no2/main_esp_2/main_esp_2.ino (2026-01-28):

/* main_esp_1.ino */

#include <freertos/FreeRTOS.h>
#include <freertos/task.h>
#include <freertos/semphr.h>

#include "WifiMng.h"
#include "BME680Mng.h"
#include "BtnMng.h"
#include "LcdMenuMng.h"
#include "LedCtrl.h"
#include "TimeMng.h"
#include "MqttMng.h"

TaskHandle_t TaskBME680_hdl;

#define DBG_SERVICE_PRINT_INTERVAL 2000UL
void DebuggerService();

void BME680_TaskFunction(void * pvParameters);

void setup() 
{
    Serial.begin(115200);
    delay(2000);

    Serial.println("=================> ESP NO.2 <==================");

    WifiMng_LoadNetworksInVector();
    TimeMng_Init();  /* ← inițializează NTP */
    LcdMng_Init();  /* initializeaza LCD + meniu */
    MqttMng_Init(); // <--- Inițializare MQTT
    BME680_Init();

    xTaskCreatePinnedToCore
    (
      BME680_TaskFunction,   /* Funcția task-ului */
      "BME680TASK",          /* Numele task-ului */
      8096,                  /* Stack size în words */
      NULL,                  /* Parametri */
      1,                     /* Prioritate */
      &TaskBME680_hdl,       /* Handle */
      0                      /* Core 0 */
    );
}

void loop() 
{
    WifiMng_MainFunction(); 
    MqttMng_MainFunction(); 
    
    LedCtrl_MainFunction();

    BtnMng_MainFunction(BTN_PIN, BtnMng_debounceTime);
    LcdMng_MainFunction();
    DebuggerService();

    delay(20); 
}

void DebuggerService()
{
    static unsigned long last_print_time = 0;
    unsigned long now = millis();

    if (now - last_print_time >= DBG_SERVICE_PRINT_INTERVAL)
    {

        /* Timestamp live */
        Serial.print("*Δt:"); Serial.print(now / 1000); Serial.print(" ");

        Serial.print("*IP:"); Serial.print((const char*)g_systemValues.wifi.ip); Serial.print(" ");
        Serial.print("RSSI:"); Serial.print(g_systemValues.wifi.rssi); Serial.print("dBm ");

        Serial.print("*T:"); Serial.print(g_systemValues.bme.temp); Serial.print("C ");
        Serial.print("H:"); Serial.print(g_systemValues.bme.hum); Serial.print("% ");
        Serial.print("P:"); Serial.print(g_systemValues.bme.pressure); Serial.print("hPa ");
        Serial.print("R:"); Serial.print(g_systemValues.bme.RkOhm); Serial.print(" kOhms");
        Serial.print("ITU:"); Serial.print(g_systemValues.bme.itu); Serial.print(" ");
        Serial.print("IAQ:"); Serial.print(g_systemValues.bme.iaq); Serial.print(" ");
        Serial.print("Alt:"); Serial.print(g_systemValues.bme.alt); Serial.print("m ");

        Serial.print("*LED:"); Serial.print(g_systemValues.led.toggled); Serial.print(" ");
        Serial.print("PWM:");  Serial.print(g_systemValues.led.pwm); Serial.print(" %");

        Serial.print("*OVD:");  Serial.print(g_systemValues.mqtt.overdrive); Serial.print(" ");
        Serial.print("LDR:");  Serial.print(g_systemValues.mqtt.light); Serial.print(" ");
        Serial.print("PWM:");  Serial.print(g_systemValues.mqtt.pwm); Serial.print(" ");

        Serial.println();
        
        last_print_time = now;
    }
}

void BME680_TaskFunction(void * pvParameters) 
{

    Serial.print("[BME680TASK]: Runs on CORE "); Serial.println(xPortGetCoreID());

    for(;;) 
    {
        BME680_MainFunction();
        vTaskDelay(pdMS_TO_TICKS(100)); 
    }
}
 

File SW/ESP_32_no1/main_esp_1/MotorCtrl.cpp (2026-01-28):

/* MotorCtrl.cpp */

#include "MotorCtrl.h"

static uint8_t last_applied_pwm = 0;
static float last_temp_threshold = 0;

void MotorCtrl_Init(void)
{
    g_systemValues.motor.running = false;

    pinMode(MOTOR_PWM_PIN, OUTPUT);

    ledcAttach(MOTOR_PWM_PIN, MOTOR_PWM_FREQ, MOTOR_PWM_RES);
    ledcWrite(MOTOR_PWM_PIN, 0);

}

void MotorCtrl_MainFunction()
{
    if (g_systemValues.wifi.mqtt_connected == true)
    {
        if (g_systemValues.mqtt.overdirve == true)
        {
            MotorCtrl_ApplyPWM(g_systemValues.mqtt.pwm);
        }
        else if (g_systemValues.mqtt.overdirve == false)
        {
            MotorCtrl_Auto();
        }
    }
    else
    {
        MotorCtrl_ApplyPWM(0);
    }

    MotorCtrl_ProcessRPM();
}

void MotorCtrl_ApplyPWM(uint8_t targetDuty)
{
    if ( g_systemValues.motor.running == false && targetDuty > 10)
    {
        MotorCtrl_Kickstart(targetDuty);
        ledcWrite(MOTOR_PWM_PIN, targetDuty);
        last_applied_pwm = targetDuty;
        MotorCtrl_CheckMotorStat(targetDuty);
    }
    else if (targetDuty < 10)
    {
        ledcWrite(MOTOR_PWM_PIN, targetDuty);
        last_applied_pwm = targetDuty;
        MotorCtrl_CheckMotorStat(targetDuty);
    }
    else 
    {
        if (targetDuty != last_applied_pwm && targetDuty < last_applied_pwm) 
        {
            MotorCtrl_Kickstart(targetDuty);
        }
        ledcWrite(MOTOR_PWM_PIN, targetDuty);
        last_applied_pwm = targetDuty;
        MotorCtrl_CheckMotorStat(targetDuty);
    }
}

void MotorCtrl_CheckMotorStat(uint8_t targetDuty)
{
    if (g_systemValues.current.voltage_V > 0.5f && g_systemValues.current.current_A >= 0.1f)
    {
        g_systemValues.motor.running = true;
        g_systemValues.motor.pwm =  (uint8_t)((uint32_t)targetDuty * 100 / PWM_FULL);
    }
    else if (targetDuty == 0)
    {
        g_systemValues.motor.running = false;
        g_systemValues.motor.pwm =  0U; 
    }
    else 
    {
        g_systemValues.motor.running = false;
        g_systemValues.motor.pwm =  0U;
    }
}

void MotorCtrl_ProcessRPM() 
{

    const float Kv = 1866.6f; 
    const float Ri = R_MOTO;     

    /* Calculate Back-EMF Eb = V_applied - (I * R_intern) */
    float drop = g_systemValues.current.current_A * Ri;
    float Eb = g_systemValues.current.voltage_V - (g_systemValues.current.current_A * Ri);

    // Serial.print("V:"); Serial.print(g_systemValues.current.voltage_V);
    // Serial.print(" | Drop:"); Serial.print(drop);
    // Serial.print(" | Eb:"); Serial.println(Eb);

    /* Filter value */ 
    if (Eb < 0 || g_systemValues.motor.running == false) 
    {
        g_systemValues.motor.rpm = 0.0f;
    } 
    else 
    {
        /* Calculate estimated RPM*/ 
        g_systemValues.motor.rpm = (float)((uint32_t)((Eb * Kv) + 0.5f));
    }

}

void MotorCtrl_Auto()
{
    float target = (float)g_systemValues.mqtt.threshold; 
    float currentTemp = g_systemValues.mqtt.temp;
    
    /* Calculate the difference (Delta T) */
    float diff = currentTemp - target; 
    g_systemValues.motor.threshold = diff; 

    /* Threshold > +2.0: Set PWM to 100% */
    if (diff >= 2.0f) 
    {
        MotorCtrl_ApplyPWM(PWM_FULL);
    }
    /* Threshold between +1.0 and +2.0: Set PWM to 75% */
    else if (diff >= 1.0f && diff < 2.0f) 
    {
        MotorCtrl_ApplyPWM(PWM_75);
    }
    /* Threshold between +0.25 and +1.0: Set PWM to 60% */
    else if (diff > 0.25f && diff < 1.0f) 
    {
        MotorCtrl_ApplyPWM(PWM_60);
    }
    /* Threshold between -0.25 and +0.25: Stop the Motor (Deadband) */
    else if (diff >= -0.25f && diff <= 0.25f) 
    {
        MotorCtrl_ApplyPWM(0);
    }
    /* Threshold between -1.0 and -0.25: Set PWM to 55% */
    else if (diff >= -1.0f && diff < -0.25f) 
    {
        MotorCtrl_ApplyPWM(PWM_55);
    }
    /* Threshold between -2.0 and -1.0: Set PWM to 50% */
    else if (diff >= -2.0f && diff < -1.0f) 
    {
        MotorCtrl_ApplyPWM(PWM_50);
    }
    /* Threshold < -2.0: Keep PWM at 45% */
    else if (diff < -2.0f) 
    {
        MotorCtrl_ApplyPWM(PWM_45);
    }
}

void MotorCtrl_Kickstart(uint8_t targetDuty)
{
    Serial.println("[KICSTART ACTIVE]");
    for (uint8_t i = 0; i < MotorCtrl_KickStartSequence_Size; i++)
    {
        if ( MotorCtrl_KickStartSequence[i] >= targetDuty)
        {
            uint8_t pace = ((uint8_t)(MotorCtrl_KickStartSequence[i] * PWM_FULL));
            ledcWrite(MOTOR_PWM_PIN, pace);
            vTaskDelay(pdMS_TO_TICKS(50));

        }
    }
    Serial.println("[KICSTART DISABLED]");
}

/* Test Functions */

void MotorCtrl_ApplyCyclicPWM(uint8_t targetDuty)
{
    uint32_t now = millis();
    MotorCtrl_CheckMotorStat(targetDuty);

    if (targetDuty >= PWM_FULL)
    {
        ledcWrite(MOTOR_PWM_PIN, PWM_FULL);
        motorPhase = MOTOR_PHASE_BOOST;
        motorPhaseTimestamp = now;
        return;
    }

    switch (motorPhase)
    {
        case MOTOR_PHASE_BOOST:
            ledcWrite(MOTOR_PWM_PIN, PWM_FULL);

            if (now - motorPhaseTimestamp >= BOOST_TIME_MS)
            {
                motorPhase = MOTOR_PHASE_HOLD;
                motorPhaseTimestamp = now;
            }
            break;

        case MOTOR_PHASE_HOLD:
            ledcWrite(MOTOR_PWM_PIN, targetDuty);

            if (now - motorPhaseTimestamp >= HOLD_TIME_MS)
            {
                motorPhase = MOTOR_PHASE_BOOST;
                motorPhaseTimestamp = now;
            }
            break;
    }
}

void MotorCtrl_TestFunction(void)
{
    static uint32_t lastChange = 0;
    static uint8_t  pwmLevelIndex = 0;

    const uint8_t pwmLevels[] =
    {
        PWM_25,
        PWM_50,
        PWM_75,
        PWM_FULL
    };

    uint32_t now = millis();

    if (now - lastChange >= 20000)
    {
        lastChange = now;

        pwmLevelIndex = (pwmLevelIndex + 1) % (sizeof(pwmLevels) / sizeof(pwmLevels[0]));

        Serial.println("--------------------------------------------------");
        Serial.printf("[Motor TEST] New target PWM: %u / 255 (%.1f %%)\n",
                      pwmLevels[pwmLevelIndex],
                      (pwmLevels[pwmLevelIndex] * 100.0f) / 255.0f);

        MotorCtrl_ResetCycle();
    }

    MotorCtrl_ApplyCyclicPWM(pwmLevels[pwmLevelIndex]);

    static uint32_t lastPrint = 0;
    if (now - lastPrint >= 500)
    {
        lastPrint = now;

        Serial.printf("[Motor PWM] Phase: %s | Target: %u | Active PWM: %u\n",
                      (motorPhase == MOTOR_PHASE_BOOST) ? "BOOST" : "HOLD",
                      pwmLevels[pwmLevelIndex],
                      (motorPhase == MOTOR_PHASE_BOOST) ? PWM_FULL : pwmLevels[pwmLevelIndex]);
    }
}

void MotorCtrl_ResetCycle(void)
{
    motorPhase = MOTOR_PHASE_BOOST;
    motorPhaseTimestamp = millis();
}

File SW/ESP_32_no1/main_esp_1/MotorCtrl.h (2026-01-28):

/* MotorCtrl.h */

#ifndef MOTOR_MNG_H
#define MOTOR_MNG_H

#include <Arduino.h>
#include <stdlib.h>
#include "Values.h"

#define R_MOTO 1.15f

#define MOTOR_PWM_PIN    5
#define MOTOR_PWM_FREQ   1000
#define MOTOR_PWM_RES    8

#define PWM_FULL         255
#define PWM_25           ((uint8_t)(0.25f * PWM_FULL))
#define PWM_45           ((uint8_t)(0.45f * PWM_FULL))
#define PWM_50           ((uint8_t)(0.50f * PWM_FULL))
#define PWM_55           ((uint8_t)(0.55f * PWM_FULL))
#define PWM_60           ((uint8_t)(0.60f * PWM_FULL))
#define PWM_75           ((uint8_t)(0.75f * PWM_FULL))

const float MotorCtrl_KickStartSequence[] = {
    0.99f, 0.98f, 0.97f, 0.96f, 0.95f, 0.94f, 0.93f, 0.92f, 0.91f, 0.90f,
    0.89f, 0.88f, 0.87f, 0.86f, 0.85f, 0.84f, 0.83f, 0.82f, 0.81f, 0.80f,
    0.79f, 0.78f, 0.77f, 0.76f, 0.75f, 0.74f, 0.73f, 0.72f, 0.71f, 0.70f,
    0.69f, 0.68f, 0.67f, 0.66f, 0.65f, 0.64f, 0.63f, 0.62f, 0.61f, 0.60f,
    0.59f, 0.58f, 0.57f, 0.56f, 0.55f, 0.54f, 0.53f, 0.52f, 0.51f, 0.50f,
    0.49f, 0.48f, 0.47f, 0.46f, 0.45f, 0.44f, 0.43f, 0.42f, 0.41f, 0.40f,
    0.39f, 0.38f, 0.37f, 0.36f, 0.35f, 0.34f, 0.33f, 0.32f, 0.31f, 0.30f,
    0.29f, 0.28f, 0.27f, 0.26f, 0.25f
};
const uint8_t MotorCtrl_KickStartSequence_Size = sizeof(MotorCtrl_KickStartSequence) / sizeof(MotorCtrl_KickStartSequence[0]);

#define BOOST_TIME_MS    100
#define HOLD_TIME_MS     400

typedef enum
{
    MOTOR_PHASE_BOOST = 0,
    MOTOR_PHASE_HOLD
} MotorPhase_t;

static MotorPhase_t motorPhase = MOTOR_PHASE_BOOST;
static uint32_t motorPhaseTimestamp = 0;

void MotorCtrl_Init();
void MotorCtrl_MainFunction();
void MotorCtrl_ApplyCyclicPWM(uint8_t targetDuty);
void MotorCtrl_ApplyPWM(uint8_t targetDuty);
void MotorCtrl_TestFunction(void);
void MotorCtrl_ResetCycle(void);
void MotorCtrl_CheckMotorStat(uint8_t targetDuty);
void MotorCtrl_ProcessRPM();
void MotorCtrl_Kickstart(uint8_t targetDuty);
void MotorCtrl_Auto();

#endif

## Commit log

2026-02-04 Revise README for Distributed Monitoring and Control System
    Updated project title and added detailed sections on hardware and software components, including diagrams and descriptions for both ESP32 nodes and the Node-RED dashboard.
2026-02-24 Rename Motor_and_LED_Control .png to Motor_and_LED_Control.png
